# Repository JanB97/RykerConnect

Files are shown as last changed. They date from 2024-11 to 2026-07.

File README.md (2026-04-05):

# RykerConnect
Addon Media Display for CanAm Ryker

> [!WARNING]
> Current Hardware Version (REV01) of the MainUnit has a hardware bug.
In my test, I did not connect the reset line of the display to a pin on the esp32. 
I did only connect it to the reset/enable pin of the esp. This seemed to be fine while testing, but with the production boards I am having problems with the initialization.
I would ***NOT*** recommend getting these boards produced right now.
> 
> **Update 05.04.2026**: It's fixed in software for the most part, it seems like it's working now, just a bit buggy on startup (you see weird or old images).
> I have created a Rev2 that uses a gpio as reset line, but this board is not tested, i have not ordered it and you will need to build the firmware yourseld, because you need to change the pinout from using no pin to IO15 for the display reset.

This Project contains a firmware for a esp32s3 that is build on PlattformIO and the Arduino Core, an Android Companion App to get data on the Display and a simple ESP32S3 Board design to fit within a 3D printed case.
I will publish all the projects; however, please keep in mind that I am neither a hardware designer nor a software engineer, so pretty much all of this is messy.
It works, but that is a miracle.
Originally I did intend for this to have many features (e.g., show the weather, maybe map navigation, and more), but my development skills are not good enough right now.

The current features are only:
- Display the current time
- Keep the time while turned off
- Display the current temperature (if Hardware is installed on the board)
- Display current battery percentage of the connected phone
- Display current battery percentage of the connected intercom
- Display 'Spotify' media information
- Display Youtube Music media information
- Display incoming notifications (mostly)
- Display current network status
- ota updated from github or with firmware.bin file.
- Settings for: Brightness, Batteries to show, notification display timeout
- Quick Screen Reset (in case it will still bug out with the newest firmware and only display on one side of the oled)

Things I want to add/fix:
- Notifications are currently mostly working, but sometimes apps do random things and I think the android app needs some work to handle that.

Things to add to REV3 Hardware:
- similar to REV2 extend "empty" space around and under temp sensor, to help it not warm up because of the casing and/or ESP32
- add 3 wire (V, GND, S) connector for external DS18B20 (technically possible with REV1 through the exposed pins

REV3 is most likely (if at all) the next hardware rev i am going to build, as my REV1 is working good enough now, and there is no reason to build rev2 without the external sensor now.

> [!NOTE]
> You will need Programming and Hardware knowlage to get this to work right now, I don't think I can really support this right now, so please ho ahead on your own risk.
> If you can and are willing to help with the board design and programming, feel free to help, I am glad for every help on this!

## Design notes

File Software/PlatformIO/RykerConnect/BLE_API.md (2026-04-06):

# RykerConnect BLE API Documentation

## Overview

The RykerConnect MainUnit uses Bluetooth Low Energy (BLE) with NimBLE stack on an ESP32. The device advertises as **"RykerConnect-MainUnit"** and uses a **6-digit numeric pairing PIN** (display-only IO capability).

- **Bonding:** Enabled (bond + MITM protection)
- **TX Power:** +9 dBm
- **HID:** Registered as Gamepad (Appearance: `0x0180`, 1 button)

## Connection Parameters

After connection, the ESP requests fast connection parameters:
- Min Interval: 7.5ms (6 × 1.25ms)
- Max Interval: 15ms (12 × 1.25ms)
- Latency: 0
- Timeout: 1000ms (100 × 10ms)

---

## BLE Watchdog

If BLE is connected but **no characteristic is written for 10 minutes** (600,000 ms), the ESP force-disconnects the client. Any write resets the watchdog timer.

---

## Quick Reference — All Characteristics

| # | Name | UUID | Permissions |
|---|---|---|---|
| 1 | Time | `a41dcc81-d45e-4445-99bb-38c37c1ef1c8` | READ, WRITE |
| 2 | Network Status | `49c7fba8-9ba7-474b-b8a5-a5431e057e23` | WRITE |
| 3 | Phone Battery | `1f74ccf5-376a-40b6-ab60-7b1c5efbf652` | WRITE |
| 4 | Intercom Battery | `85546838-6ae5-45cb-aa2f-4c8af50d17d4` | WRITE |
| 5 | Media Data | `dcadc0d8-24ed-40ed-952b-5d1c872a69aa` | WRITE, WRITE\_NR |
| 6 | Notification | `755cf5b1-ded3-4c7b-a6fc-8c5ce2f99fdb` | WRITE + ENC + AUTHEN |
| 7 | Display Brightness | `7bc28f30-10bc-46e2-b84b-96e0545c2f5c` | READ, WRITE |
| 8 | Screen Selection | `62dbb02d-4a3a-452e-b753-02bcb2272b9d` | READ, WRITE |
| 9 | Settings | `05f7c3e4-daac-4953-8c71-20eacdf0c7a1` | READ + ENC + AUTHEN, WRITE + ENC + AUTHEN |
| 10 | Firmware Update (OTA) | `1d1306c5-98d9-4998-8dfd-35136295575f` | WRITE + ENC + AUTHEN |
| 11 | Firmware Reset | `18cb54fe-45e8-4819-a262-24b731c8b236` | WRITE + AUTHEN |
| 12 | Display Reinit | `3a6e4b2c-8f71-4d09-b5a3-c7e2f1d08a94` | WRITE |
| 13 | Firmware Version | `fb2385da-5290-4513-bb0c-6d0b21de619a` | READ |
| 14 | Hardware Version | `3ae9aece-1b67-4281-a53b-748adf23f484` | READ |
| 15 | Volume | `c4e83b7d-5a12-4f8e-b9d6-3e7f1c2a4b8d` | WRITE, WRITE\_NR |

---

## Service

| Name | UUID |
|---|---|
| RykerConnect Service | `db7ba582-229a-4b96-9000-cf0f69f86f73` |

---

## Characteristics

### 1. Time

| Property | Value |
|---|---|
| UUID | `a41dcc81-d45e-4445-99bb-38c37c1ef1c8` |
| Permissions | READ, WRITE |

**Write** – Set the RTC clock time.

| Byte | Type | Description |
|---|---|---|
| 0 | uint8_t | Hour (0–23) |
| 1 | uint8_t | Minute (0–59) |
| 2 | uint8_t | Second (0–59) |

Total: **3 bytes**

**Read** – Returns a placeholder string (not the current time).

---

### 2. Network Status

| Property | Value |
|---|---|
| UUID | `49c7fba8-9ba7-474b-b8a5-a5431e057e23` |
| Permissions | WRITE |

**Write** – Send mobile network signal and type.

| Byte | Type | Description |
|---|---|---|
| 0 | uint8_t | Signal strength (raw value) |
| 1 | uint8_t | Network type code |

Total: **2 bytes** (uint16_t, little-endian)

Network type codes:
| Code | Display |
|---|---|
| 0 | `!` (no signal) |
| 1 | `G` (GPRS) |
| 2 | `E` (EDGE) |
| 3 | `3G` |
| 4 | `H` (HSPA) |
| 5 | `H+` (HSPA+) |
| 6 | `4G` (LTE) |
| 7 | `4G+` (LTE-A) |
| 8 | `5G` |
| 9 | `5G+` |

---

### 3. Phone Battery

| Property | Value |
|---|---|
| UUID | `1f74ccf5-376a-40b6-ab60-7b1c5efbf652` |
| Permissions | WRITE |

**Write** – Send phone battery level and charging status.

| Byte | Type | Description |
|---|---|---|
| 0 | int8_t | Battery level (0–100, or negative) |
| 1 | uint8_t | Charging status (0 = not charging, 1 = charging) |

Total: **2 bytes** (int16_t, little-endian)

**Low battery warning:** If level ≤ `low_battery_threshold_phone`, a popup is shown. The warning triggers **only once per threshold crossing** — the flag resets only when the battery rises above the threshold again. Popup duration = `warning_popup_duration` seconds.

---

### 4. Intercom Battery

| Property | Value |
|---|---|
| UUID | `85546838-6ae5-45cb-aa2f-4c8af50d17d4` |
| Permissions | WRITE |

**Write** – Send intercom battery level.

| Byte | Type | Description |
|---|---|---|
| 0 | uint8_t | Battery level (0–100) |

Total: **1 byte** (int8_t)

**Low battery warning:** Same one-time-per-crossing logic as for phone battery. No charging status for intercom.

---

### 5. Media Data

| Property | Value |
|---|---|
| UUID | `dcadc0d8-24ed-40ed-952b-5d1c872a69aa` |
| Permissions | WRITE, WRITE_NR (write without response) |

**Write** – Send current media playback state.

| Byte | Type | Description |
|---|---|---|
| 0 | uint8_t | Playstate: 0 = paused, 1 = playing |
| 1–2 | uint16_t (LE) | Current position in seconds |
| 3–4 | uint16_t (LE) | Total track length in seconds |
| 5+ | String | Title + `0x03` (ETX separator) + Artist |

Total: **5+ bytes** (minimum 5 without title/artist)

All fields are **little-endian**, consistent with all other characteristics.

String format for bytes 5+:
```
<Title>\x03<Artist>
```

---

### 6. Notification

| Property | Value |
|---|---|
| UUID | `755cf5b1-ded3-4c7b-a6fc-8c5ce2f99fdb` |
| Permissions | WRITE (encrypted + authenticated) |

**Write** – Display a notification popup on the device.

String format:
```
<Type>\x03<Title>\x03<Text>
```

Fields are separated by `0x03` (ETX byte). All fields are UTF-8 strings. The notification is displayed for a configurable duration (`notification_interval` in settings).

---

### 7. Display Brightness

| Property | Value |
|---|---|
| UUID | `7bc28f30-10bc-46e2-b84b-96e0545c2f5c` |
| Permissions | READ, WRITE |

**Write** – Set display brightness (contrast) for both OLEDs.

| Byte | Type | Description |
|---|---|---|
| 0 | uint8_t | Brightness (0–255) |

**Read** – Returns the current brightness value (uint8_t).

---

### 8. Screen Selection

| Property | Value |
|---|---|
| UUID | `62dbb02d-4a3a-452e-b753-02bcb2272b9d` |
| Permissions | READ, WRITE |

**Write** – Switch the active screen layout.

| Byte | Type | Description |
|---|---|---|
| 0 | uint8_t | Screen index |

Screen indices:
| Value | Screen |
|---|---|
| 0 | Default (fullscreen clock left, temperature right) |
| 1 | Media screen |
| 2 | Split screen |

**Read** – Returns the current screen index (uint8_t).

---

### 9. Settings

| Property | Value |
|---|---|
| UUID | `05f7c3e4-daac-4953-8c71-20eacdf0c7a1` |
| Permissions | READ (encrypted + authenticated), WRITE (encrypted + authenticated) |

**Read** – Returns the full EEPROM_Struct (all settings as raw bytes). The struct is packed, so it can be directly parsed byte by byte.

**EEPROM_Struct layout (read response):**

| Offset | Size | Type | Field | Description |
|---|---|---|---|---|
| **Brightness** |
| 0 | 1 | bool | adaptive_brightness | Adaptive brightness enabled |
| 1 | 1 | uint8_t | display_brightness | Display brightness (0–255) |
| 2–3 | 2 | uint16_t (LE) | auto_brightness_adc_low | ADC value (0–4095) below which min brightness is applied (default: 200) |
| 4–5 | 2 | uint16_t (LE) | auto_brightness_adc_high | ADC value (0–4095) above which max brightness is applied (default: 3500) |
| **Screen** |
| 6 | 1 | uint8_t | screen | Active screen index (0=Default, 1=Media, 2=Split) |
| 7 | 1 | uint8_t | sub_screen | Sub-screen index |
| **Battery Icon** |
| 8 | 1 | bool | battery_icon_selection[0] | Show phone battery icon |
| 9 | 1 | bool | battery_icon_selection[1] | Show intercom battery icon |
| 10 | 1 | bool | battery_icon_selection[2] | (reserved) |
| 11 | 1 | bool | battery_icon_selection[3] | (reserved) |
| 12 | 1 | int8_t | battery_icon_first | First battery icon to show |
| 13–16 | 4 | uint32_t (LE) | battery_icon_interval | Battery icon rotation interval (ms) |
| **Low Battery Warning** |
| 17 | 1 | uint8_t | low_battery_threshold_phone | Phone low-battery warning threshold % (default: 20) |
| 18 | 1 | uint8_t | low_battery_threshold_intercom | Intercom low-battery warning threshold % (default: 20) |
| 19 | 1 | uint8_t | warning_popup_duration | Warning popup display duration in seconds (default: 5) |
| **Other** |
| 20–23 | 4 | uint32_t (LE) | notification_interval | Notification display duration (ms) |
| 24–27 | 4 | float (LE) | temp_calibration | Temperature offset in °C (subtracted from sensor) |
| **Reserved** |
| 28–37 | 10 | uint8_t[10] | reserved | Reserved for future use |
| **CRC** |
| 38–41 | 4 | uint32_t (LE) | crc | CRC32 checksum |

Total: **42 bytes**

**Write** – Update all settings. Send **38 bytes** (struct without CRC). The CRC is recalculated automatically. Settings are persisted to flash (NVS/Preferences).

Write payload (38 bytes = struct size minus CRC):

| Offset | Size | Type | Field | Notes |
|---|---|---|---|---|
| 0 | 1 | bool | adaptive_brightness | |
| 1 | 1 | uint8_t | display_brightness | |
| 2–3 | 2 | uint16_t (LE) | auto_brightness_adc_low | Send `0` to keep current value |
| 4–5 | 2 | uint16_t (LE) | auto_brightness_adc_high | Send `0` to keep current value |
| 6 | 1 | uint8_t | screen | |
| 7 | 1 | uint8_t | sub_screen | |
| 8–11 | 4 | bool[4] | battery_icon_selection | |
| 12 | 1 | int8_t | battery_icon_first | |
| 13–16 | 4 | uint32_t (LE) | battery_icon_interval | |
| 17 | 1 | uint8_t | low_battery_threshold_phone | |
| 18 | 1 | uint8_t | low_battery_threshold_intercom | |
| 19 | 1 | uint8_t | warning_popup_duration | Seconds (default: 5) |
| 20–23 | 4 | uint32_t (LE) | notification_interval | |
| 24–27 | 4 | float (LE) | temp_calibration | Temperature offset in °C (subtracted from sensor) |
| 28–37 | 10 | uint8_t[10] | reserved | Send `0` |

**Note:** `crc` is NOT included in the write payload. The ESP expects exactly `sizeof(EEPROM_Struct) - sizeof(uint32_t)` = **38 bytes**. ADC thresholds are only updated if `adc_high > adc_low` and both are non-zero. `temp_calibration` is applied directly and subtracted from every sensor reading.

---

### 10. Firmware Update (OTA)

| Property | Value |
|---|---|
| UUID | `1d1306c5-98d9-4998-8dfd-35136295575f` |
| Permissions | WRITE (encrypted + authenticated) |

**Write** – Start WiFi and OTA update process.

String format (two variants):

**Browser-based OTA (no download URL):**
```
<SSID>\x03<Password>
```
The ESP connects to WiFi and starts a web server at `http://RykerConnect.local` for manual firmware upload via browser.

**Direct download OTA:**
```
<SSID>\x03<Password>\x03<Firmware_URL>
```
The ESP connects to WiFi and automatically downloads & flashes the firmware from the given URL. Both `http://` and `https://` are supported (GitHub Releases URLs work). Falls back to browser OTA on failure.

Fields are separated by `0x03` (ETX byte).

---

### 11. Firmware Reset

| Property | Value |
|---|---|
| UUID | `18cb54fe-45e8-4819-a262-24b731c8b236` |
| Permissions | WRITE (authenticated) |

**Write** – Factory reset the device (if correct PIN is provided), or cancel a pending reset.

| Byte | Type | Description |
|---|---|---|
| 0–1 | uint16_t (LE) | Reset PIN (or `0` to cancel) |

- **Value `0`:** Cancels a pending reset and hides the reset popup on the display.
- **Correct PIN:** Settings are reset and ESP restarts.
- **Wrong PIN:** A new PIN is generated and displayed.

A random 4-digit PIN (1000–9999) is generated at boot and shown on the display when a wrong PIN is sent.

---

### 12. Display Reinit

| Property | Value |
|---|---|
| UUID | `3a6e4b2c-8f71-4d09-b5a3-c7e2f1d08a94` |
| Permissions | WRITE |

**Write** – Reinitialize both OLED displays. Useful when a display fails to initialize at boot.

Send any value (content is ignored). The ESP will:
1. Reset CS pins
2. Initialize displays with slow SPI clock (8 MHz)
3. Re-initialize with fast SPI clock (60 MHz)
4. Restore brightness from saved settings

---

### 13. Firmware Version

| Property | Value |
|---|---|
| UUID | `fb2385da-5290-4513-bb0c-6d0b21de619a` |
| Permissions | READ |

**Read** – Returns the firmware version as a raw 16-bit integer.

| Byte | Type | Description |
|---|---|---|
| 0–1 | uint16_t (LE) | Firmware version (e.g. `0x0004` = V00.04) |

The version value corresponds to the `VERSION` compile-time constant. To display it in `Vxx.yy` format:
- High byte = major (`(version >> 8) & 0xFF`)
- Low byte = minor (`version & 0xFF`)

---

### 14. Hardware Version

| Property | Value |
|---|---|
| UUID | `3ae9aece-1b67-4281-a53b-748adf23f484` |
| Permissions | READ |

**Read** – Returns the hardware version as a UTF-8 string (e.g. `"ESP32S3-REV01"`).

---

### 15. Volume

| Property | Value |
|---|---|
| UUID | `c4e83b7d-5a12-4f8e-b9d6-3e7f1c2a4b8d` |
| Permissions | WRITE |

**Write** – Send the current volume level. Displays a popup with percentage and progress bar (duration configurable via `warning_popup_duration` setting).

| Byte | Type | Description |
|---|---|---|
| 0 | uint8_t | Volume level (0 = Mute, 1–100 = percentage) |

Total: **1 byte**

---

## Data Encoding Notes

- **Byte order:** All multi-byte integers use **little-endian**.
- **String separator:** `0x03` (ETX) is used as field delimiter in all string-based characteristics.
- **String encoding:** UTF-8.

## Behavior Notes

**Low Battery Warning:** Triggers once when battery first falls below the threshold. The trigger flag resets only after the battery recovers above the threshold — preventing repeated popups on every BLE update.

**Volume Popup:** Shown on every Volume write. Duration = `warning_popup_duration` seconds.

**Auto-Brightness:** EMA-smoothed ADC reading (α=0.05, 100 ms interval) from light sensor on ADC pin 7. Mapped linearly from `[adc_low, adc_high]` → brightness `[25, 255]`. Minimum brightness is **25** (never goes below). Manual Brightness characteristic writes are ignored while `adaptive_brightness` is enabled.

---

## Android / Kotlin Implementation

### Constants

```kotlin
object RykerBLE {
    const val DEVICE_NAME            = "RykerConnect-MainUnit"
    const val SERVICE_UUID           = "db7ba582-229a-4b96-9000-cf0f69f86f73"
    const val TIME_UUID              = "a41dcc81-d45e-4445-99bb-38c37c1ef1c8"
    const val NETWORK_UUID           = "49c7fba8-9ba7-474b-b8a5-a5431e057e23"
    const val PHONE_BATTERY_UUID     = "1f74ccf5-376a-40b6-ab60-7b1c5efbf652"
    const val INTERCOM_BATTERY_UUID  = "85546838-6ae5-45cb-aa2f-4c8af50d17d4"
    const val MEDIA_DATA_UUID        = "dcadc0d8-24ed-40ed-952b-5d1c872a69aa"
    const val NOTIFICATION_UUID      = "755cf5b1-ded3-4c7b-a6fc-8c5ce2f99fdb"
    const val BRIGHTNESS_UUID        = "7bc28f30-10bc-46e2-b84b-96e0545c2f5c"
    const val SCREEN_UUID            = "62dbb02d-4a3a-452e-b753-02bcb2272b9d"
    const val SETTINGS_UUID          = "05f7c3e4-daac-4953-8c71-20eacdf0c7a1"
    const val FIRMWARE_UPDATE_UUID   = "1d1306c5-98d9-4998-8dfd-35136295575f"
    const val FIRMWARE_RESET_UUID    = "18cb54fe-45e8-4819-a262-24b731c8b236"
    const val DISPLAY_REINIT_UUID    = "3a6e4b2c-8f71-4d09-b5a3-c7e2f1d08a94"
    const val FIRMWARE_VERSION_UUID  = "fb2385da-5290-4513-bb0c-6d0b21de619a"
    const val HARDWARE_VERSION_UUID  = "3ae9aece-1b67-4281-a53b-748adf23f484"
    const val VOLUME_UUID            = "c4e83b7d-5a12-4f8e-b9d6-3e7f1c2a4b8d"
    const val SETTINGS_READ_SIZE     = 42  // full struct including CRC
    const val SETTINGS_WRITE_SIZE    = 38  // struct without CRC
}
```

### Write Helper

```kotlin
/** Queue BLE writes — only one can be in-flight at a time. */
fun BluetoothGatt.writeChar(uuid: String, data: ByteArray) {
    val svc  = getService(UUID.fromString(RykerBLE.SERVICE_UUID)) ?: return
    val char = svc.getCharacteristic(UUID.fromString(uuid)) ?: return
    char.writeType = BluetoothGattCharacteristic.WRITE_TYPE_DEFAULT
    char.value = data
    writeCharacteristic(char)
}

/** Fire-and-forget write (no BLE ACK) — use for frequent updates like Volume. */
fun BluetoothGatt.writeCharNR(uuid: String, data: ByteArray) {
    val svc  = getService(UUID.fromString(RykerBLE.SERVICE_UUID)) ?: return
    val char = svc.getCharacteristic(UUID.fromString(uuid)) ?: return
    char.writeType = BluetoothGattCharacteristic.WRITE_TYPE_NO_RESPONSE
    char.value = data
    writeCharacteristic(char)
}

// Android 13+ (API 33):
fun BluetoothGatt.writeChar33(uuid: String, data: ByteArray, noResponse: Boolean = false) {
    val svc  = getService(UUID.fromString(RykerBLE.SERVICE_UUID)) ?: return
    val char = svc.getCharacteristic(UUID.fromString(uuid)) ?: return
    val type = if (noResponse) BluetoothGattCharacteristic.WRITE_TYPE_NO_RESPONSE
               else BluetoothGattCharacteristic.WRITE_TYPE_DEFAULT
    writeCharacteristic(char, data, type)
}
```

### Sending Time

```kotlin
fun sendTime(gatt: BluetoothGatt) {
    val now = Calendar.getInstance()
    gatt.writeChar(RykerBLE.TIME_UUID, byteArrayOf(
        now.get(Calendar.HOUR_OF_DAY).toByte(),
        now.get(Calendar.MINUTE).toByte(),
        now.get(Calendar.SECOND).toByte()
    ))
}
```

### Sending Network Status

```kotlin
fun sendNetwork(gatt: BluetoothGatt, signalBars: Int, typeCode: Int) {
    // signalBars: 0–5 (icon level), typeCode: 0–9 (see network type table)
    gatt.writeChar(RykerBLE.NETWORK_UUID, byteArrayOf(
        signalBars.toByte(),
        typeCode.toByte()
    ))
}
```

### Sending Phone Battery

```kotlin
fun sendPhoneBattery(gatt: BluetoothGatt, level: Int, isCharging: Boolean) {
    val data = ByteBuffer.allocate(2).order(ByteOrder.LITTLE_ENDIAN)
        .put(level.toByte())
        .put(if (isCharging) 1.toByte() else 0.toByte())
        .array()
    gatt.writeChar(RykerBLE.PHONE_BATTERY_UUID, data)
}
```

### Sending Intercom Battery

```kotlin
fun sendIntercomBattery(gatt: BluetoothGatt, level: Int) {
    gatt.writeChar(RykerBLE.INTERCOM_BATTERY_UUID, byteArrayOf(level.toByte()))
}
```

### Sending Media Data

```kotlin
fun sendMediaData(
    gatt: BluetoothGatt,
    playing: Boolean,
    positionSec: Int,
    lengthSec: Int,
    title: String,
    artist: String
) {
    val titleBytes  = title.toByteArray(Charsets.UTF_8)
    val artistBytes = artist.toByteArray(Charsets.UTF_8)
    val buf = ByteBuffer.allocate(5 + titleBytes.size + 1 + artistBytes.size)
        .order(ByteOrder.LITTLE_ENDIAN)
    buf.put(if (playing) 1.toByte() else 0.toByte())  // [0] playstate
    buf.putShort(positionSec.toShort())                 // [1-2] little-endian
    buf.putShort(lengthSec.toShort())                   // [3-4] little-endian
    buf.put(titleBytes)
    buf.put(0x03.toByte())                              // ETX separator
    buf.put(artistBytes)
    gatt.writeChar(RykerBLE.MEDIA_DATA_UUID, buf.array())
}
```

### Sending a Notification

```kotlin
fun sendNotification(gatt: BluetoothGatt, type: String, title: String, text: String) {
    // type examples: "WhatsApp", "Instagram", "Discord", "Gmail", "Messages"
    gatt.writeChar(
        RykerBLE.NOTIFICATION_UUID,
        "$type\u0003$title\u0003$text".toByteArray(Charsets.UTF_8)
    )
}
```

### Setting Brightness

```kotlin
fun setBrightness(gatt: BluetoothGatt, brightness: Int) {
    // 0–255. No effect while adaptive_brightness is enabled.
    gatt.writeChar(RykerBLE.BRIGHTNESS_UUID, byteArrayOf(brightness.coerceIn(0, 255).toByte()))
}
```

### Setting Screen

```kotlin
fun setScreen(gatt: BluetoothGatt, screenIndex: Int) {
    // 0 = Default (clock+temp), 1 = Media, 2 = Split
    gatt.writeChar(RykerBLE.SCREEN_UUID, byteArrayOf(screenIndex.toByte()))
}
```

### Sending Volume

```kotlin
fun sendVolume(gatt: BluetoothGatt, volumePercent: Int) {
    // Use WRITE_NO_RESPONSE for fast, frequent volume updates (no BLE round-trip ACK).
    // 0 = Mute, 1–100 = percentage. Shows popup for warning_popup_duration seconds.
    gatt.writeCharNR(RykerBLE.VOLUME_UUID, byteArrayOf(volumePercent.coerceIn(0, 100).toByte()))
}
```

### Reading Settings (42 bytes)

```kotlin
fun parseSettings(data: ByteArray): RykerSettings {
    require(data.size >= 42) { "Settings response must be 42 bytes" }
    val buf = ByteBuffer.wrap(data).order(ByteOrder.LITTLE_ENDIAN)
    return RykerSettings(
        adaptiveBrightness    = buf.get().toInt() != 0,           // [0]
        displayBrightness     = buf.get().toInt() and 0xFF,        // [1]
        adcLow                = buf.short.toInt() and 0xFFFF,      // [2-3]
        adcHigh               = buf.short.toInt() and 0xFFFF,      // [4-5]
        screen                = buf.get().toInt() and 0xFF,         // [6]
        subScreen             = buf.get().toInt() and 0xFF,         // [7]
        batteryIcon0          = buf.get().toInt() != 0,            // [8]
        batteryIcon1          = buf.get().toInt() != 0,            // [9]
        // [10],[11] reserved bools — read and discard
        also { buf.get(); buf.get() },
        batteryIconFirst      = buf.get().toInt(),                  // [12] signed
        batteryIconInterval   = buf.int,                            // [13-16] ms
        lowBatteryPhone       = buf.get().toInt() and 0xFF,         // [17] %
        lowBatteryIntercom    = buf.get().toInt() and 0xFF,         // [18] %
        warningPopupDuration  = buf.get().toInt() and 0xFF,         // [19] seconds
        notificationInterval  = buf.int,                            // [20-23] ms
        tempCalibration       = buf.float,                          // [24-27]
        // [28-37] reserved — skip, [38-41] CRC — skip
    )
}
```

### Writing Settings (38 bytes)

```kotlin
fun buildSettingsPayload(s: RykerSettings): ByteArray {
    val data = ByteArray(RykerBLE.SETTINGS_WRITE_SIZE)  // 38 bytes, no CRC
    val buf  = ByteBuffer.wrap(data).order(ByteOrder.LITTLE_ENDIAN)
    buf.put(if (s.adaptiveBrightness) 1 else 0)        // [0]
    buf.put(s.displayBrightness.toByte())               // [1]
    buf.putShort(s.adcLow.toShort())                    // [2-3]  0 = keep current
    buf.putShort(s.adcHigh.toShort())                   // [4-5]  0 = keep current
    buf.put(s.screen.toByte())                          // [6]
    buf.put(s.subScreen.toByte())                       // [7]
    buf.put(if (s.batteryIcon0) 1 else 0)              // [8]
    buf.put(if (s.batteryIcon1) 1 else 0)              // [9]
    buf.put(0)                                          // [10] reserved
    buf.put(0)                                          // [11] reserved
    buf.put(s.batteryIconFirst.toByte())                // [12]
    buf.putInt(s.batteryIconInterval)                   // [13-16] ms
    buf.put(s.lowBatteryPhone.toByte())                 // [17] %
    buf.put(s.lowBatteryIntercom.toByte())              // [18] %
    buf.put(s.warningPopupDuration.toByte())            // [19] seconds
    buf.putInt(s.notificationInterval)                  // [20-23] ms
    buf.putFloat(0f)                                    // [24-27] temp_calibration: ESP ignores writes
    repeat(10) { buf.put(0) }                           // [28-37] reserved
    return data
}

fun writeSettings(gatt: BluetoothGatt, s: RykerSettings) {
    gatt.writeChar(RykerBLE.SETTINGS_UUID, buildSettingsPayload(s))
}
```

### Reading Firmware / Hardware Version

```kotlin
// Trigger a read — handle result in onCharacteristicRead()
fun readVersions(gatt: BluetoothGatt) {
    val svc = gatt.getService(UUID.fromString(RykerBLE.SERVICE_UUID)) ?: return
    gatt.readCharacteristic(svc.getCharacteristic(UUID.fromString(RykerBLE.FIRMWARE_VERSION_UUID)))
    // Wait for onCharacteristicRead before issuing next read!
}

// In BluetoothGattCallback.onCharacteristicRead():
override fun onCharacteristicRead(gatt: BluetoothGatt, char: BluetoothGattCharacteristic, status: Int) {
    if (status != BluetoothGatt.GATT_SUCCESS) return
    val data = char.value
    when (char.uuid.toString().lowercase()) {
        RykerBLE.FIRMWARE_VERSION_UUID.lowercase() -> {
            val buf   = ByteBuffer.wrap(data).order(ByteOrder.LITTLE_ENDIAN)
            val ver   = buf.short.toInt() and 0xFFFF  // e.g. 0x0006
            val major = (ver shr 8) and 0xFF           // 0
            val minor = ver and 0xFF                   // 6
            val text  = "v$major.$minor"               // "v0.6"
        }
        RykerBLE.HARDWARE_VERSION_UUID.lowercase() -> {
            val hw = String(data, Charsets.UTF_8)      // "ESP32S3-REV01"
        }
        RykerBLE.SETTINGS_UUID.lowercase() -> {
            val settings = parseSettings(data)         // 42 bytes
        }
    }
}
```

### OTA Update

```kotlin
// Variant A — Browser upload (no URL):
fun startOtaBrowser(gatt: BluetoothGatt, ssid: String, password: String) {
    gatt.writeChar(RykerBLE.FIRMWARE_UPDATE_UUID, "$ssid\u0003$password".toByteArray())
    // Device connects to WiFi and shows IP on screen.
    // Open http://<ip> (or http://RykerConnect.local) in browser, upload .bin file.
}

// Variant B — Direct download (HTTP and HTTPS supported, e.g. GitHub Releases):
fun startOtaDownload(gatt: BluetoothGatt, ssid: String, password: String, url: String) {
    gatt.writeChar(
        RykerBLE.FIRMWARE_UPDATE_UUID,
        "$ssid\u0003$password\u0003$url".toByteArray()
    )
}
```

### Factory Reset

```kotlin
fun sendResetPin(gatt: BluetoothGatt, pin: Int) {
    // pin = 0 → cancel and hide popup
    // pin = 4-digit value shown on display → reset all settings and reboot
    // any other value → new PIN generated and shown on display
    val data = ByteBuffer.allocate(2).order(ByteOrder.LITTLE_ENDIAN)
        .putShort(pin.toShort()).array()
    gatt.writeChar(RykerBLE.FIRMWARE_RESET_UUID, data)
}
```

### Reinitialize Displays

```kotlin
fun reinitDisplays(gatt: BluetoothGatt) {
    gatt.writeChar(RykerBLE.DISPLAY_REINIT_UUID, byteArrayOf(0x01))
}
```

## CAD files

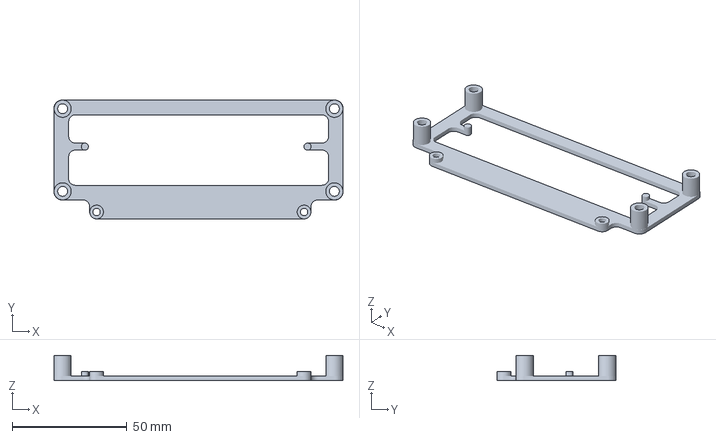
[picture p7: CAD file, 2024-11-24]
CAD/3MF/Developement/RykerConnect - DevMount-Mount V1.3mf
125.9 x 51.8 x 11.0 mm

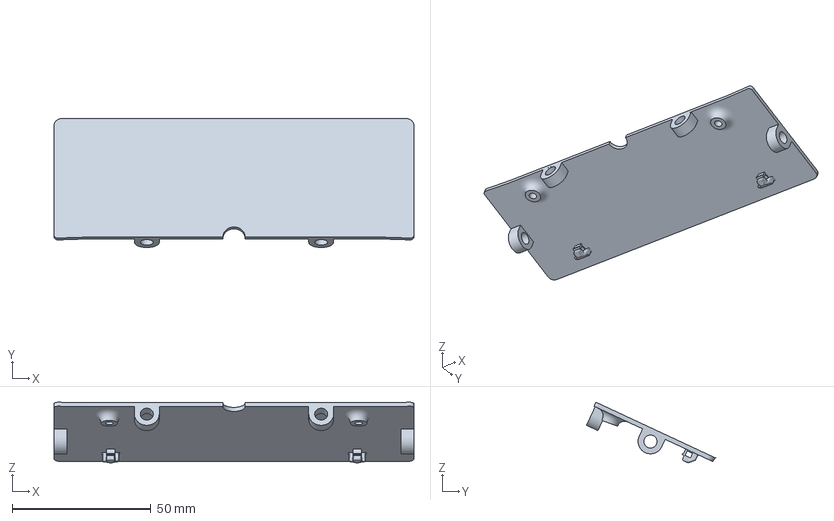
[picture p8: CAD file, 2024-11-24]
CAD/3MF/RykerMount/PCB-Mount.-Back V1.3mf
130.0 x 46.6 x 21.9 mm
Körper10
Körper11
Körper7

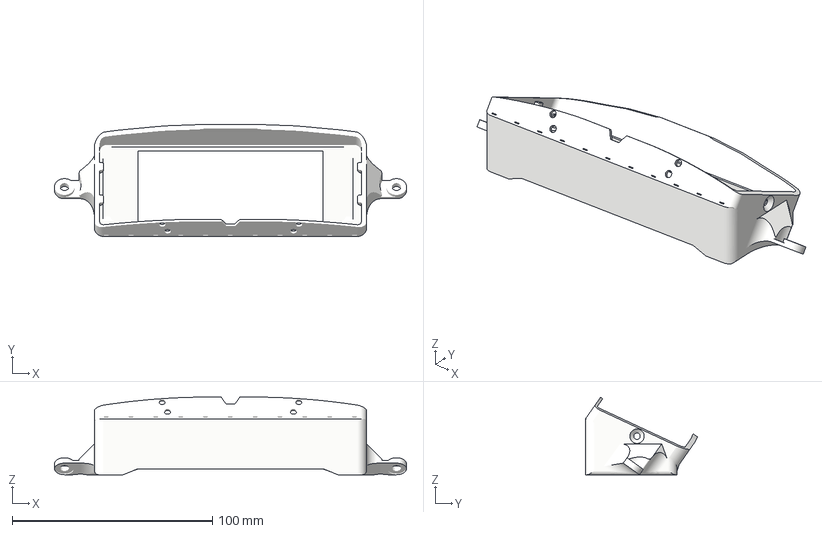
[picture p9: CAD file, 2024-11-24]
CAD/3MF/RykerMount/DisplayCover V1.3mf
176.0 x 56.0 x 38.8 mm

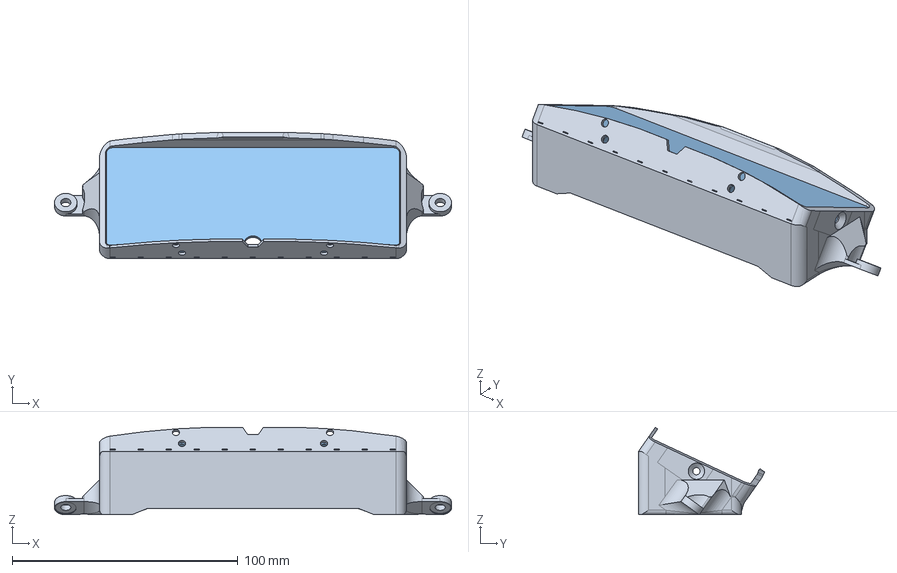
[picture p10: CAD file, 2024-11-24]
CAD/STEP/RykerConnect - Mount v1.step
176.0 x 56.0 x 38.8 mm
DisplayCover
PCB-Mount.-Back

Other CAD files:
CAD/STEP/RykerConnect - DevMount v1.step
CAD/Source/RykerConnect - DevMount v1.FCStd

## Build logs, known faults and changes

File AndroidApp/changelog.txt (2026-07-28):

V1.4.0: 
- support for multiple intercoms with a priority order: if several are connected, the topmost one reports its battery
- new app settings: Material You colors and a toggle for the debug Card
- battery reporting is now configurable: charge state changes are sent instantly while the level is polled at an adjustable 30 s to 10 min
- significantly fewer background wakeups by removing a permanent media session poll and idling the intercom loop when nothing is selected
- fix: connecting an intercom while the main unit was disconnected crashed the app, and the battery value was sent to the wrong device
- morph animations for settings, service and intercom now actually animate, plus support for the predictive back gesture
- updated to Android 17, Gradle 9.6.1 and Kotlin 2.4.10  

V1.3.1:
- bluetooth stability improvements.

V1.3.0:
- support Firmware V00.06 features and protocol changes
- new Design for Settings pages
- allow changing wifi credentials from DebugCard
- allow stopping parts of the service

V1.2.1:
- add debug option to send firmware update to BLE-address withouth device connection

V1.2:
- fix wifi credentials not beeing saved / not beeing display
- added changelog in firmware update view.
- add button listener to "Update available" tag
- bugfixes to "select / reselect device" function

V1.1:
- fix wifi credential fields and state
- fix latest firmware was not selected

V1.0:
- initial full release

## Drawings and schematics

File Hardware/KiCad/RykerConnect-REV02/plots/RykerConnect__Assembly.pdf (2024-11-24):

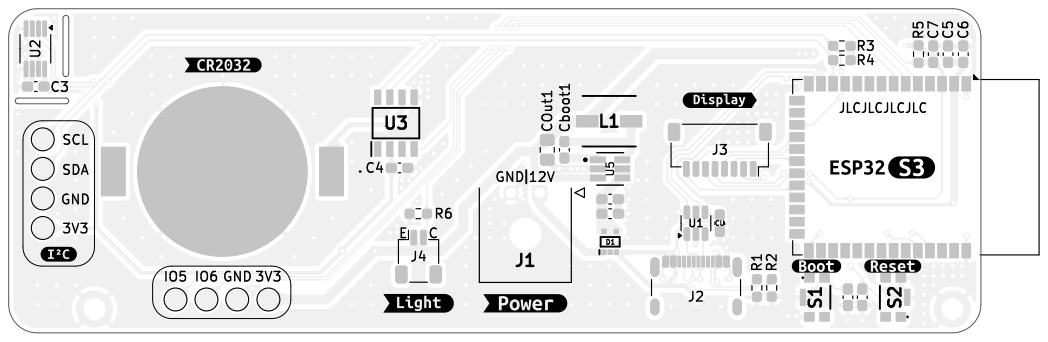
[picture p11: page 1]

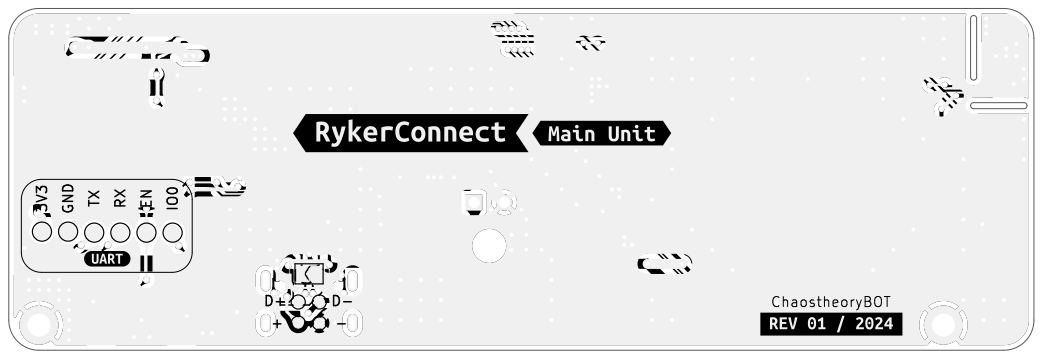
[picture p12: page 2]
D Date: KiCad; E.D.A. 8.0.1 Size: A4; Rev:; Id: 1/1 Title: File: RykerConnect.kicad_pcb Sheet: AISLER; Project; ID: QIOOLVKT; ChaostheoryBOT ³V³ GND TXRXENIO⁰

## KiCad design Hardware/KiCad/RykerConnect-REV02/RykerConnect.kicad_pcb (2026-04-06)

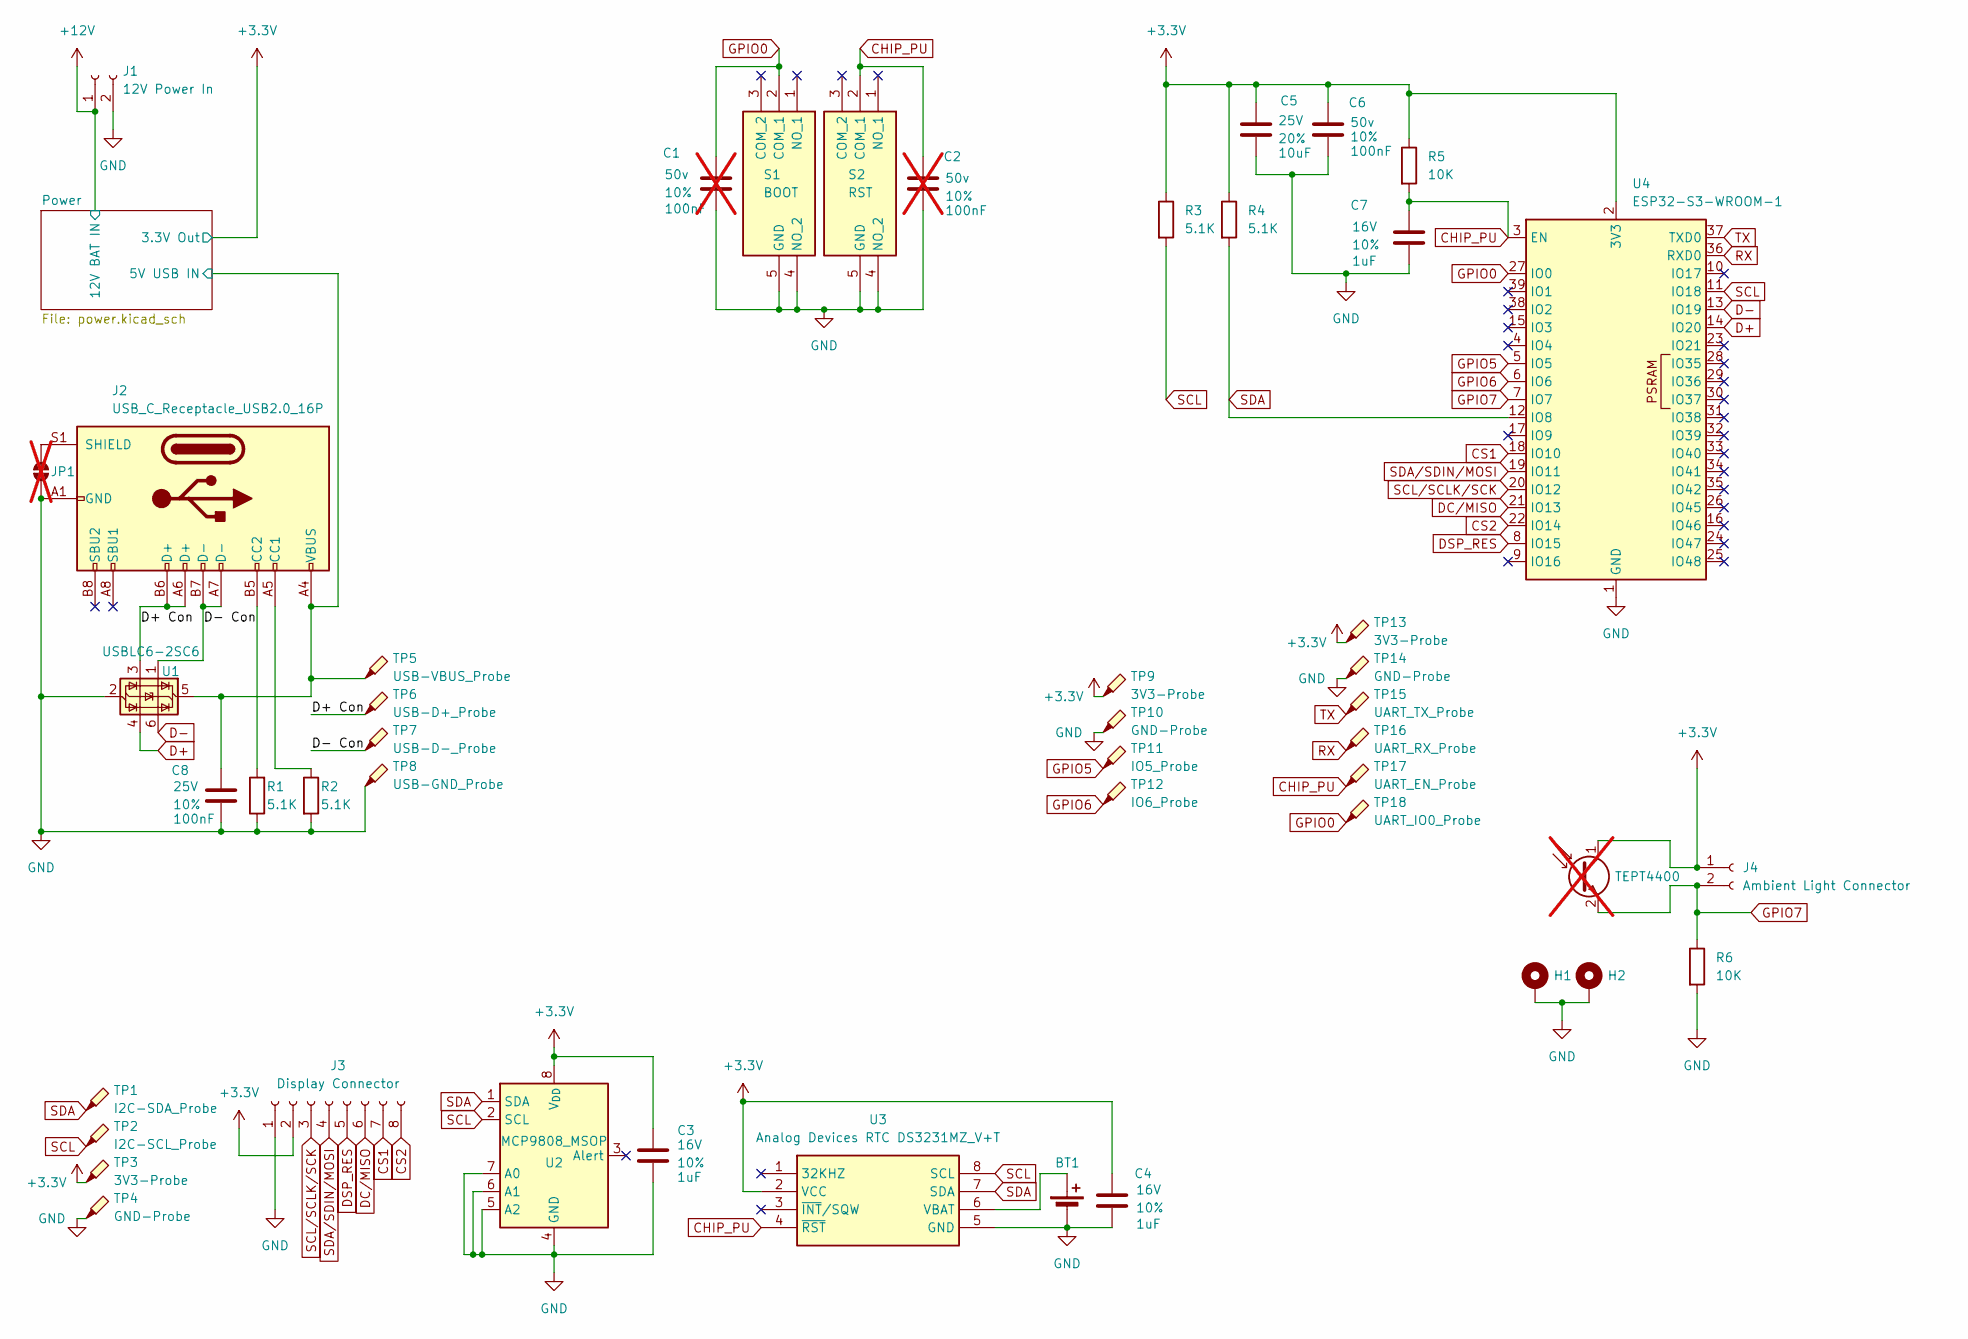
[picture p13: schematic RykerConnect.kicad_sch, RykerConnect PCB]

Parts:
BT1: Holders Linx CR2032; BATHLD001
C1, C2: 100nF; C_0603_1608Metric_Pad1.08x0.95mm_HandSolder; Voltage 50v; Tolerance 10%; not fitted
C3, C4, C7: 1uF; C_0603_1608Metric_Pad1.08x0.95mm_HandSolder; Voltage 16V; Tolerance 10%
C5: 10uF; C_0603_1608Metric_Pad1.08x0.95mm_HandSolder; Voltage 25V; Tolerance 20%
C6: 100nF; C_0603_1608Metric_Pad1.08x0.95mm_HandSolder; Voltage 50v; Tolerance 10%
C8: 100nF; C_0603_1608Metric_Pad1.08x0.95mm_HandSolder; Voltage 25V; Tolerance 10%
H1, H2: MountingHole_Pad; MountingHole_2.2mm_M2_ISO14580_Pad_TopBottom
J1: 12V Power In; 43650-02_00,01,02_
J2: USB_C_Receptacle_USB2.0_16P; USB_C_Receptacle_GCT_USB4105-xx-A_16P_TopMnt_Horizontal
J3: Display Connector; JST_SH_SM08B-SRSS-TB_1x08-1MP_P1.00mm_Horizontal
J4: Ambient Light Connector; JST_SH_SM02B-SRSS-TB_1x02-1MP_P1.00mm_Horizontal
JP1: SolderJumper_2_Open; R_0603_1608Metric_Pad0.98x0.95mm_HandSolder; not fitted
Q1: TEPT4400; LED_D3.0mm_Clear; not fitted
R1, R2, R3, R4: 5.1K; R_0805_2012Metric_Pad1.20x1.40mm_HandSolder
R5: 10K; R_0805_2012Metric_Pad1.20x1.40mm_HandSolder; Tolerance 1%
R6: 10K; R_0805_2012Metric_Pad1.20x1.40mm_HandSolder
S1: BOOT; 435451019820; Mouser Part Number 710-435451019820
S2: RST; 435451019820; Mouser Part Number 710-435451019820
TP1: I2C-SDA_Probe; TestPoint_Pad_D2.0mm
TP2: I2C-SCL_Probe; TestPoint_Pad_D2.0mm
TP3, TP9: 3V3-Probe; TestPoint_Pad_D2.0mm
TP4, TP10: GND-Probe; TestPoint_Pad_D2.0mm
TP5: USB-VBUS_Probe; TestPoint_Pad_D1.0mm
TP6: USB-D+_Probe; TestPoint_Pad_D1.0mm
TP7: USB-D-_Probe; TestPoint_Pad_D1.0mm
TP8: USB-GND_Probe; TestPoint_Pad_D1.0mm
TP11: IO5_Probe; TestPoint_Pad_D2.0mm
TP12: IO6_Probe; TestPoint_Pad_D2.0mm
TP13: 3V3-Probe; TestPoint_Pad_D1.5mm
TP14: GND-Probe; TestPoint_Pad_D1.5mm
TP15: UART_TX_Probe; TestPoint_Pad_D1.5mm
TP16: UART_RX_Probe; TestPoint_Pad_D1.5mm
TP17: UART_EN_Probe; TestPoint_Pad_D1.5mm
TP18: UART_IO0_Probe; TestPoint_Pad_D1.5mm
U1: USBLC6-2SC6; SOT-23-6
U2: MCP9808_MSOP; MSOP-8_3x3mm_P0.65mm
U3: Analog Devices RTC DS3231MZ_V+T; SOIC127P600X175-8N; Mouser Part Number 700-DS3231MZ/V+T
U4: ESP32-S3-WROOM-1

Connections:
+3.3V: C3.1, C4.1, C5.1, C6.1, J3.2, J4.1, Q1.1 (C), R3.1, R4.1, R5.1, TP3.1 (1_1), TP9.1 (1_1), TP13.1 (1_1), U2.8 (V_{DD}), U3.2 (VCC), U4.2 (3V3); also elsewhere on the board
+12V: J1.1; also elsewhere on the board
/D+ Con: J2.A6 (D+), J2.B6 (D+), TP6.1 (1_1), U1.3 (I/O2)
/D- Con: J2.A7 (D-), J2.B7 (D-), TP7.1 (1_1), U1.1 (I/O1)
/Power/5V USB IN: C8.1, J2.A4 (VBUS), J2.A9 (VBUS), J2.B4 (VBUS), J2.B9 (VBUS), TP5.1 (1_1), U1.5 (VBUS); also elsewhere on the board
CHIP_PU: C2.1, C7.1, R5.2, S2.2 (COM_1), TP17.1 (1_1), U3.4 (~RST), U4.3 (EN)
CS1: J3.7, U4.18 (IO10)
CS2: J3.8, U4.22 (IO14)
D+: U1.4 (I/O2), U4.14 (IO20)
D-: U1.6 (I/O1), U4.13 (IO19)
DC/MISO: J3.6, U4.21 (IO13)
DSP_RES: J3.5, U4.8 (IO15)
GND: BT1.2 (-), C1.2, C2.2, C3.2, C4.2, C5.2, C6.2, C7.2, C8.2, H1.1 (1_1), H2.1 (1_1), J1.2, J2.A1 (GND), J2.A12 (GND), J2.B1 (GND), J2.B12 (GND), J3.1, JP1.1 (A), R1.1, R2.2, R6.2, S1.4 (NO_2), S1.5 (GND), S2.4 (NO_2), S2.5 (GND), TP4.1 (1_1), TP8.1 (1_1), TP10.1 (1_1), TP14.1 (1_1), U1.2 (GND), U2.4 (GND), U2.5 (A2), U2.6 (A1), U2.7 (A0), U3.5 (GND), U4.1 (GND), U4.40 (GND), U4.41 (GND); also elsewhere on the board
GPIO0: C1.1, S1.2 (COM_1), TP18.1 (1_1), U4.27 (IO0)
GPIO5: TP11.1 (1_1), U4.5 (IO5)
GPIO6: TP12.1 (1_1), U4.6 (IO6)
GPIO7: J4.2, Q1.2 (E), R6.1, U4.7 (IO7)
unnamed: BT1.1 (+), U3.6 (VBAT)
unnamed: J2.A5 (CC1), R2.1
unnamed: J2.B5 (CC2), R1.2
unnamed: J2.S1 (SHIELD), JP1.2 (B)
RX: TP16.1 (1_1), U4.36 (RXD0)
SCL: R3.2, TP2.1 (1_1), U2.2 (SCL), U3.8 (SCL), U4.11 (IO18)
SCL/SCLK/SCK: J3.3, U4.20 (IO12)
SDA: R4.2, TP1.1 (1_1), U2.1 (SDA), U3.7 (SDA), U4.12 (IO8)
SDA/SDIN/MOSI: J3.4, U4.19 (IO11)
TX: TP15.1 (1_1), U4.37 (TXD0)

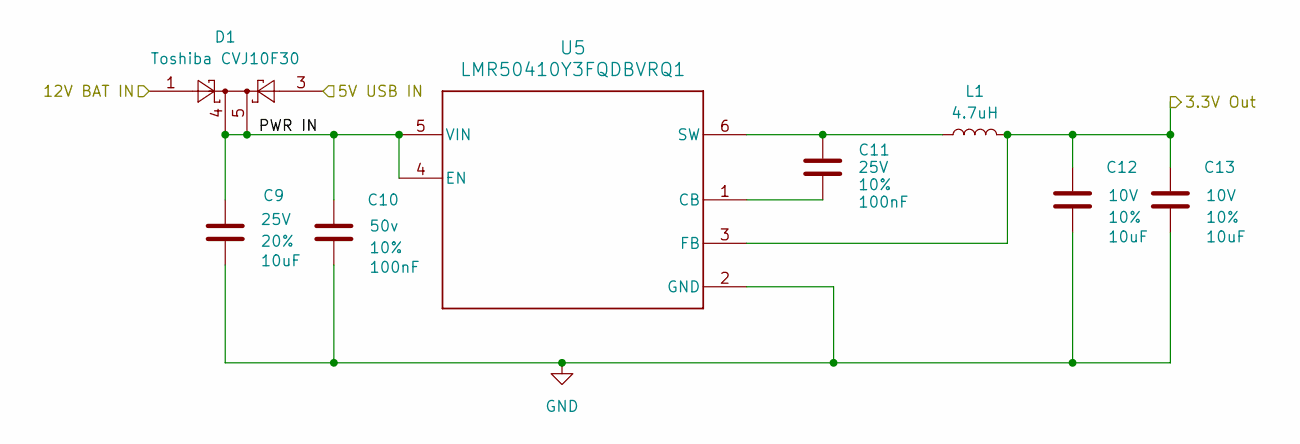
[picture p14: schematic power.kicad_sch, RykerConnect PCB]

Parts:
C9: 10uF; C_0603_1608Metric_Pad1.08x0.95mm_HandSolder; Voltage 25V; Tolerance 20%
C10: 100nF; C_0603_1608Metric_Pad1.08x0.95mm_HandSolder; Voltage 50v; Tolerance 10%
C11: 100nF; C_0603_1608Metric_Pad1.08x0.95mm_HandSolder; Voltage 25V; Tolerance 10%
C12, C13: 10uF; C_0805_2012Metric_Pad1.18x1.45mm_HandSolder; Voltage 10V; Tolerance 10%
D1: Toshiba CVJ10F30; SOTFL65P210X75-5N
L1: 4.7uH; INDPM5653X430N
U5: LMR50410Y3FQDBVRQ1; DBV0006A-IPC_A

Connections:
+3.3V: C12.1, C13.1, L1.2, U5.3 (FB); also elsewhere on the board
+12V: D1.1; also elsewhere on the board
/Power/5V USB IN: D1.3; also elsewhere on the board
/Power/PWR IN: C9.1, C10.1, D1.4, D1.5, U5.4 (EN), U5.5 (VIN)
GND: C9.2, C10.2, C12.2, C13.2, U5.2 (GND); also elsewhere on the board
unnamed: C11.2, U5.1 (CB)
unnamed: C11.1, L1.1, U5.6 (SW)

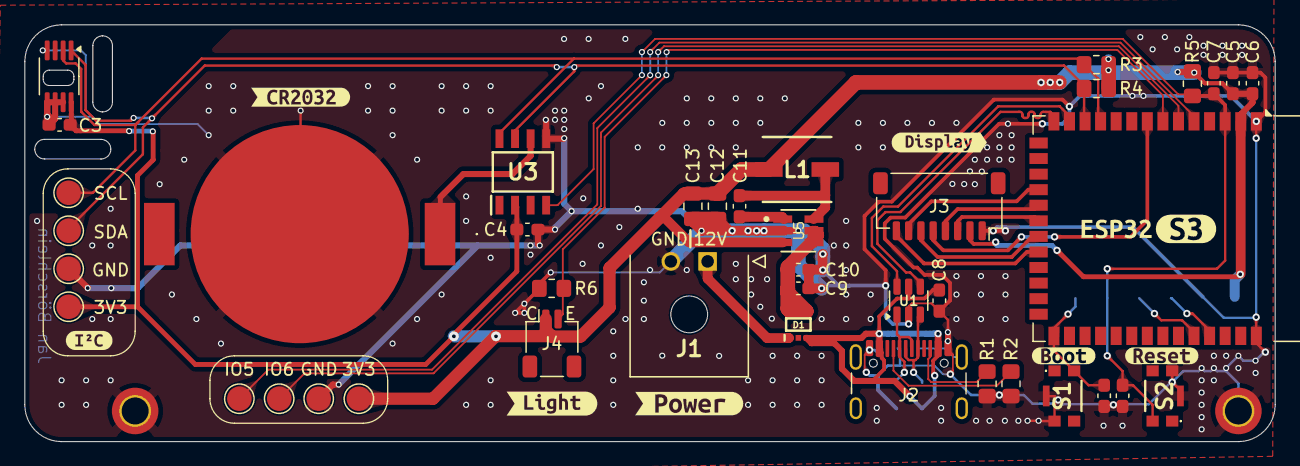
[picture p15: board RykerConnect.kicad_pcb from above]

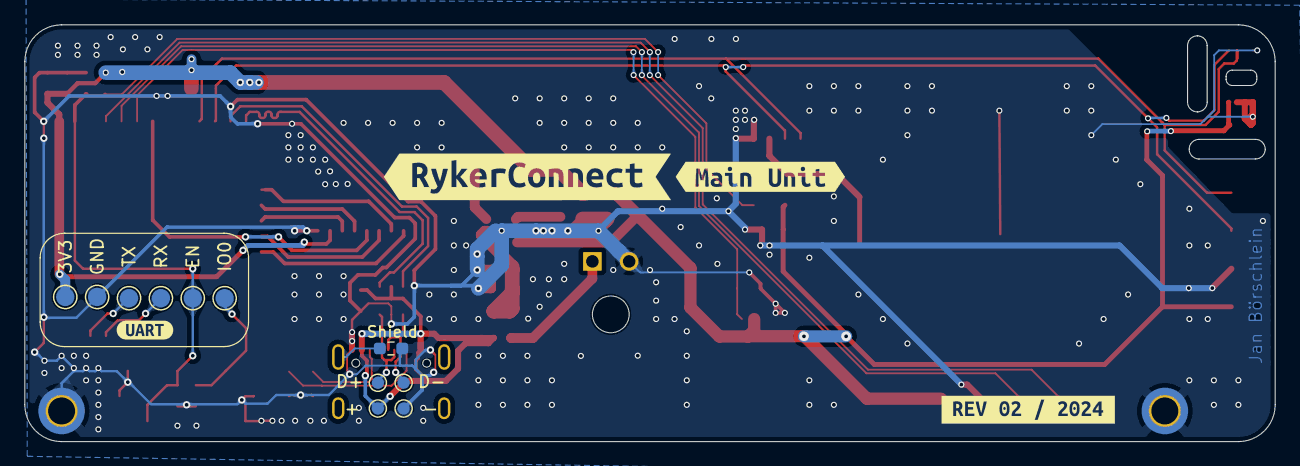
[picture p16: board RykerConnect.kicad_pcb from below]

Board: 2 copper layers, 102.0 x 34.0 mm, 67 parts (16 on the bottom side), 30 nets.

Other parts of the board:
kibuzzard-6647CFBD: G***; kibuzzard-6647CFBD
kibuzzard-66281C1F: G***; kibuzzard-66281C1F
kibuzzard-66281DA5: G***; kibuzzard-66281DA5
kibuzzard-66281FA1: G***; kibuzzard-66281FA1
kibuzzard-66282B71: G***; kibuzzard-66282B71
kibuzzard-66296C5A: G***; kibuzzard-66296C5A
kibuzzard-662805BB: G***; kibuzzard-662805BB
kibuzzard-662805C3: G***; kibuzzard-662805C3
kibuzzard-6628061E: G***; kibuzzard-6628061E
kibuzzard-6628064B: G***; kibuzzard-6628064B
kibuzzard-6628065E: G***; kibuzzard-6628065E
kibuzzard-66280634: G***; kibuzzard-66280634
kibuzzard-66281340: G***; kibuzzard-66281340

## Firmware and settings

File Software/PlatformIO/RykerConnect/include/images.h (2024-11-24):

#pragma once
#include <Arduino.h>

#define network_width 16
#define network_height 16
static unsigned char network0_bits[] = {
   0x00, 0xc0, 0x00, 0xa0, 0x00, 0x90, 0x00, 0x98, 0x00, 0x94, 0x00, 0x92,
   0x00, 0x93, 0x80, 0x92, 0x40, 0x92, 0x60, 0x92, 0x50, 0x92, 0x48, 0x92,
   0x4c, 0x92, 0x4a, 0x92, 0x49, 0x92, 0xff, 0xff };
static unsigned char network1_bits[] = {
   0x00, 0xc0, 0x00, 0xa0, 0x00, 0x90, 0x00, 0x98, 0x00, 0x94, 0x00, 0x92,
   0x00, 0x93, 0x80, 0x92, 0x40, 0x92, 0x60, 0x92, 0x50, 0x92, 0x48, 0x92,
   0x4c, 0x92, 0x4e, 0x92, 0x4f, 0x92, 0xff, 0xff };
static unsigned char network2_bits[] = {
   0x00, 0xc0, 0x00, 0xa0, 0x00, 0x90, 0x00, 0x98, 0x00, 0x94, 0x00, 0x92,
   0x00, 0x93, 0x80, 0x92, 0x40, 0x92, 0x60, 0x92, 0x70, 0x92, 0x70, 0x92,
   0x74, 0x92, 0x76, 0x92, 0x77, 0x92, 0xff, 0xff };
static unsigned char network3_bits[] = {
   0x00, 0xc0, 0x00, 0xa0, 0x00, 0x90, 0x00, 0x98, 0x00, 0x94, 0x00, 0x92,
   0x00, 0x93, 0x80, 0x93, 0x80, 0x93, 0xa0, 0x93, 0xb0, 0x93, 0xb0, 0x93,
   0xb4, 0x93, 0xb6, 0x93, 0xb7, 0x93, 0xff, 0xff };
static unsigned char network4_bits[] = {
   0x00, 0xc0, 0x00, 0xa0, 0x00, 0x90, 0x00, 0x98, 0x00, 0x9c, 0x00, 0x9c,
   0x00, 0x9d, 0x80, 0x9d, 0x80, 0x9d, 0xa0, 0x9d, 0xb0, 0x9d, 0xb0, 0x9d,
   0xb4, 0x9d, 0xb6, 0x9d, 0xb7, 0x9d, 0xff, 0xff };
static unsigned char network5_bits[] = {
   0x00, 0xc0, 0x00, 0xe0, 0x00, 0xe0, 0x00, 0xe8, 0x00, 0xec, 0x00, 0xec,
   0x00, 0xed, 0x80, 0xed, 0x80, 0xed, 0xa0, 0xed, 0xb0, 0xed, 0xb0, 0xed,
   0xb4, 0xed, 0xb6, 0xed, 0xb7, 0xed, 0xff, 0xff };



#define phone_16_width 10
#define phone_16_height 16
static unsigned char phone_16_bits[] PROGMEM = {
   0xfc, 0x00, 0x02, 0x01, 0x32, 0x01, 0x02, 0x01, 0x02, 0x01, 0x02, 0x01,
   0x02, 0x01, 0x02, 0x01, 0x02, 0x01, 0x02, 0x01, 0x02, 0x01, 0x02, 0x01,
   0x02, 0x01, 0x02, 0x01, 0x02, 0x01, 0xfc, 0x00 };

#define headset_16_width 10
#define headset_16_height 16
static unsigned char headset_16_bits[] PROGMEM = {
   0x00, 0x00, 0x7c, 0x00, 0x86, 0x01, 0x02, 0x01, 0x01, 0x02, 0x01, 0x02,
   0x01, 0x02, 0x03, 0x03, 0x03, 0x03, 0x03, 0x03, 0x03, 0x03, 0x00, 0x02,
   0x30, 0x02, 0xf0, 0x03, 0x30, 0x00, 0x00, 0x00 };

#define charging_width 5
#define charging_height 8
static unsigned char charging_bits[] PROGMEM = {0x04,0x0e,0x1b,0x00,0x00,0x04,0x0e,0x1b};

#define charging1_width 5
#define charging1_height 10
static unsigned char charging1_bits[] PROGMEM  = {0x10,0x18,0x0c,0x06,0x1e,0x0f,0x0c,0x06,0x03,0x01};


#define unkown_device_16_width 10
#define unkown_device_16_height 16
static unsigned char unkown_device_16_bits[] PROGMEM = {
   0xfe, 0x01, 0x01, 0x02, 0x79, 0x02, 0x01, 0x02, 0x01, 0x02, 0x79, 0x02,
   0xcd, 0x02, 0xcd, 0x02, 0xc1, 0x02, 0x61, 0x02, 0x31, 0x02, 0x31, 0x02,
   0x01, 0x02, 0x31, 0x02, 0x01, 0x02, 0xfe, 0x01 };


#define bluetooth_16_width 16
#define bluetooth_16_height 16
static unsigned char bluetooth_16_bits[] PROGMEM = {
   0x00, 0x00, 0x80, 0x00, 0x80, 0x01, 0x80, 0x02, 0x80, 0x04, 0xa0, 0x04,
   0xc0, 0x02, 0x80, 0x01, 0x80, 0x01, 0xc0, 0x02, 0xa0, 0x04, 0x80, 0x04,
   0x80, 0x02, 0x80, 0x01, 0x80, 0x00, 0x00, 0x00 };
#define bluetooth_16_verbunden_width 16
#define bluetooth_16_verbunden_height 16
static unsigned char bluetooth_16_verbunden_bits[] PROGMEM = {
   0x00, 0x00, 0x80, 0x00, 0x80, 0x01, 0x80, 0x02, 0x80, 0x04, 0xa0, 0x04,
   0xc0, 0x02, 0x8c, 0x31, 0x8c, 0x31, 0xc0, 0x02, 0xa0, 0x04, 0x80, 0x04,
   0x80, 0x02, 0x80, 0x01, 0x80, 0x00, 0x00, 0x00 };

/* SPOTIFY
#define spotify_30_width 30
#define spotify_30_height 30
static unsigned char spotify_30_bits[] PROGMEM = {
   0x00, 0xf0, 0x03, 0x00, 0x00, 0xfe, 0x1f, 0x00, 0x80, 0xff, 0x7f, 0x00,
   0xc0, 0xff, 0xff, 0x00, 0xe0, 0xff, 0xff, 0x01, 0xf0, 0xff, 0xff, 0x03,
   0xf8, 0xff, 0xff, 0x07, 0xfc, 0xff, 0xff, 0x0f, 0xfc, 0xff, 0xff, 0x0f,
   0x3e, 0x00, 0xf0, 0x1f, 0x1e, 0x00, 0x80, 0x1f, 0x3e, 0xfe, 0x01, 0x1e,
   0xfe, 0xff, 0x1f, 0x1e, 0xff, 0xff, 0x7f, 0x3e, 0x7f, 0x00, 0xf8, 0x3f,
   0x7f, 0x00, 0xe0, 0x3f, 0xff, 0xff, 0x83, 0x3f, 0xfe, 0xff, 0x9f, 0x1f,
   0xfe, 0x03, 0xff, 0x1f, 0xfe, 0x00, 0xf8, 0x1f, 0xfe, 0xfc, 0xe0, 0x1f,
   0xfc, 0xff, 0xe7, 0x0f, 0xfc, 0xff, 0xff, 0x0f, 0xf8, 0xff, 0xff, 0x07,
   0xf0, 0xff, 0xff, 0x03, 0xe0, 0xff, 0xff, 0x01, 0xc0, 0xff, 0xff, 0x00,
   0x80, 0xff, 0x7f, 0x00, 0x00, 0xfe, 0x1f, 0x00, 0x00, 0xe0, 0x01, 0x00 };
   */


#define musik_20_width 15
#define musik_20_height 20
static unsigned char musik_20_bits[] PROGMEM = {
   0x80, 0x03, 0x80, 0x0f, 0x80, 0x7f, 0x80, 0x7f, 0x80, 0x7f, 0x80, 0x78,
   0x80, 0x00, 0x80, 0x00, 0x80, 0x00, 0x80, 0x00, 0x80, 0x00, 0x80, 0x00,
   0x80, 0x00, 0xc0, 0x00, 0xfc, 0x00, 0xfe, 0x00, 0xff, 0x00, 0xff, 0x00,
   0x7e, 0x00, 0x3c, 0x00 };


#define notification_20_width 20
#define notification_20_height 20
static unsigned char notification_20_bits [] PROGMEM = {
	0x00, 0x06, 0x00, 0x00, 0x06, 0x00, 0x80, 0x1f, 0x00, 0xc0, 0x3f, 0x00, 0xe0, 0x7f, 0x00, 0xe0, 
	0x7f, 0x00, 0xf0, 0xff, 0x00, 0xf0, 0xff, 0x00, 0xf0, 0xff, 0x00, 0xf0, 0xff, 0x00, 0xf0, 0xff, 
	0x00, 0xf0, 0xff, 0x00, 0xf8, 0xff, 0x01, 0xf8, 0xff, 0x01, 0xfc, 0xff, 0x03, 0xfc, 0xff, 0x03, 
	0xfc, 0xff, 0x03, 0x00, 0x08, 0x00, 0x80, 0x1f, 0x00, 0x00, 0x0f, 0x00
};

static unsigned char mail_20_bits [] PROGMEM = {
	0x00, 0x00, 0x00, 0x00, 0x00, 0x00, 0x00, 0x00, 0x00, 0xfe, 0xff, 0x07, 0xff, 0xff, 0x0f, 0xff, 
	0xff, 0x0f, 0xfb, 0xff, 0x0d, 0xf7, 0x7f, 0x0f, 0x9f, 0x9f, 0x0f, 0x3f, 0xc7, 0x0f, 0x3f, 0xc0, 
	0x0f, 0xdf, 0xb9, 0x0f, 0xef, 0x7f, 0x0f, 0xf7, 0xff, 0x0e, 0xff, 0xff, 0x0f, 0xff, 0xff, 0x0f, 
	0xfe, 0xff, 0x07, 0x00, 0x00, 0x00, 0x00, 0x00, 0x00, 0x00, 0x00, 0x00
};

const unsigned char whatsapp_20_bits [] PROGMEM = {
	0x80, 0x1f, 0x00, 0xe0, 0x7f, 0x00, 0x38, 0xc0, 0x01, 0x1c, 0x80, 0x03, 0x0c, 0x00, 0x03, 0x46, 
	0x00, 0x06, 0xe6, 0x00, 0x04, 0xe3, 0x00, 0x0c, 0xe3, 0x00, 0x0c, 0xc3, 0x00, 0x0c, 0xc3, 0x00, 
	0x0c, 0x83, 0x11, 0x0c, 0x02, 0x7f, 0x0c, 0x06, 0x7c, 0x06, 0x06, 0x10, 0x06, 0x06, 0x00, 0x03, 
	0x06, 0x80, 0x01, 0x7e, 0xe0, 0x00, 0xff, 0x7f, 0x00, 0x03, 0x0f, 0x00
};

const unsigned char chat_20_bits [] PROGMEM = {
	0x00, 0x00, 0x00, 0xc0, 0x3f, 0x00, 0xf0, 0xff, 0x00, 0xf8, 0xff, 0x01, 0xfc, 0xff, 0x03, 0xfe, 
	0xff, 0x07, 0xfe, 0xff, 0x07, 0xfe, 0xff, 0x0f, 0xdf, 0xb9, 0x0f, 0x8f, 0x19, 0x0f, 0xdf, 0xb9, 
	0x0f, 0xff, 0xff, 0x0f, 0xfe, 0xff, 0x07, 0xfe, 0xff, 0x07, 0xfc, 0xff, 0x03, 0xfe, 0xff, 0x01, 
	0xfe, 0xff, 0x00, 0xfe, 0x3f, 0x00, 0x0f, 0x00, 0x00, 0x00, 0x00, 0x00
};

const unsigned char discord_20_bits [] PROGMEM = {
	0x00, 0x00, 0x00, 0x00, 0x00, 0x00, 0x40, 0x20, 0x00, 0xf8, 0xff, 0x01, 0xf8, 0xff, 0x01, 0xfc, 
	0xff, 0x03, 0xfc, 0xff, 0x03, 0xfe, 0xff, 0x07, 0xfe, 0xff, 0x07, 0x1f, 0x8f, 0x0f, 0x1f, 0x8f, 
	0x0f, 0x1f, 0x8f, 0x0f, 0xbf, 0xcf, 0x0f, 0xff, 0xff, 0x0f, 0xff, 0xff, 0x0f, 0x9e, 0x9f, 0x07, 
	0x3c, 0xc0, 0x03, 0x00, 0x00, 0x00, 0x00, 0x00, 0x00, 0x00, 0x00, 0x00
};
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

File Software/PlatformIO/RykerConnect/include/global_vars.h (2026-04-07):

#pragma once

#include <Arduino.h>
#include <U8g2lib.h>
#include <SPI.h>
#include <DS3231.h>
#include <Preferences.h>
#include <mcp9808.h>
#include <freertos/semphr.h>

#define DEBUG
#define SPLASHSCREEN

#define VERSION 0x0007
#define HARDWARE_VERSION "ESP32S3-REV01"

#define OLED_WIDTH 320
#define OLED_HEIGHT 132

#define FIRSTSCROLL_INTERVAL 5000
#define SCROLL_INTERVAL 800
#define RESET_INTERVAL 45000
#define TIME_INTERVAL 1000
#define TEMP_INTERVAL 30000


#define SUN	0
#define SUN_CLOUD  1
#define CLOUD 2
#define RAIN 3
#define THUNDER 4


#pragma region BLE UUIDS

#define SERVICE_UUID "db7ba582-229a-4b96-9000-cf0f69f86f73"

#define TIME_UUID "a41dcc81-d45e-4445-99bb-38c37c1ef1c8"
#define NETWORK_UUID "49c7fba8-9ba7-474b-b8a5-a5431e057e23"
#define PHONE_BATTERY_UUID "1f74ccf5-376a-40b6-ab60-7b1c5efbf652"
#define INTERCOM_BATTERY_UUID "85546838-6ae5-45cb-aa2f-4c8af50d17d4"
#define MEDIA_DATA_UUID "dcadc0d8-24ed-40ed-952b-5d1c872a69aa"
#define NOTIFICATION_UUID "755cf5b1-ded3-4c7b-a6fc-8c5ce2f99fdb"


#define SCREEN_UUID "62dbb02d-4a3a-452e-b753-02bcb2272b9d"
#define DISPLAY_BRIGHTNESS_UUID "7bc28f30-10bc-46e2-b84b-96e0545c2f5c"
#define SETTINGS_UUID "05f7c3e4-daac-4953-8c71-20eacdf0c7a1"
#define FIRMWARE_UPDATE_UUID "1d1306c5-98d9-4998-8dfd-35136295575f"
#define FIRMWARE_RESET_UUID "18cb54fe-45e8-4819-a262-24b731c8b236"
#define DISPLAY_REINIT_UUID "3a6e4b2c-8f71-4d09-b5a3-c7e2f1d08a94"
#define FIRMWARE_VERSION_UUID "fb2385da-5290-4513-bb0c-6d0b21de619a"
#define HARDWARE_VERSION_UUID "3ae9aece-1b67-4281-a53b-748adf23f484"
#define VOLUME_UUID "c4e83b7d-5a12-4f8e-b9d6-3e7f1c2a4b8d"

#pragma endregion  


//U8G2_SSD1322_NHD_256X64_F_4W_HW_SPI u8g2(U8G2_R0, /* cs=*/ 5, /* dc=*/ 4, /* reset=*/ -1);
extern U8G2_SSD1320_160X132_F_4W_HW_SPI u8g2_0; 
extern U8G2_SSD1320_160X132_F_4W_HW_SPI u8g2_1; 
extern U8G2 *u8g2_current;
extern u8g2_uint_t offset;


extern DS3231 RTC;
extern MCP9808 ts;
extern const int lightSensorPin;
extern String global_time;
extern float global_temp;
extern unsigned long previousMusicMillis;  // will store last time LED was updated
extern unsigned long previousBatteryIconMillis; //Change Battery Icon
extern unsigned long previousResetMillis; //Change Battery Icon
extern unsigned long previousTimeMillis;
extern unsigned long previousTempMillis;
extern int8_t batteryIconSelection;

extern uint16_t resetPin;


extern int8_t phone_battery_level;
extern int8_t intercom_battery_level;
extern bool phone_battery_status;
extern bool intercom_battery_status;
extern const unsigned short musicInterval;
extern uint8_t network_signal;
extern String network_type;
extern bool blConnected;
extern uint8_t screenToDisplay;
extern bool pairingActive;
extern uint32_t pairingPin;
extern unsigned long pairingConnectTime;

extern SemaphoreHandle_t dataMutex;

#pragma region Firmware Update

#define WIFI_HOSTNAME "RykerConnect"
extern bool firmwareUpdateEnabled;
extern bool firmwareDownloadAttempted;
extern int8_t otaDownloadPercent;
extern String wifiIPAddress;
extern String firmwareDownloadUrl;

#pragma endregion

#pragma region Notification Variables

extern unsigned long previousNotificationMillis;
extern bool notificationDisplayed;

extern String notificationType;
extern String notificationTitle;
extern String notificationText;

#pragma endregion

#pragma region Music Variables
extern bool playstate;
extern uint16_t music_timer;
extern uint16_t music_length;
extern String music_title;
extern String music_artist;

extern uint8_t scroll_title;
extern uint8_t scroll_artist;
extern bool scroll_title_en;
extern bool scroll_artist_en;
extern unsigned long previousScrollTitleMillis;
extern unsigned short scrollTitleInterval;
extern unsigned long previousScrollArtistMillis;
extern unsigned short scrollArtistInterval;
#pragma endregion

#pragma region Settings

#define ADAPTIVE_BRIGHTNESS         0
#define DISPLAY_BRIGHTNESS          148
#define SCREEN_SELECTION            1
#define SUB_SCREEN_SELECTION        0
#define BATTERY_ICON_SELECTION1     1
#define BATTERY_ICON_SELECTION2     1
#define BATTERY_ICON_SELECTION3     0
#define BATTERY_ICON_SELECTION4     0
#define BATTERY_ICON_FIRST          0
#define BATTERY_ICON_INTERVAL       30000
#define NOTIFICATION_INTERVAL       20000
#define LOW_BATTERY_THRESHOLD_PHONE_DEFAULT    20
#define LOW_BATTERY_THRESHOLD_INTERCOM_DEFAULT 20
#define AUTO_BRIGHTNESS_ADC_LOW_DEFAULT         200
#define AUTO_BRIGHTNESS_ADC_HIGH_DEFAULT        3500
#define WARNING_POPUP_DURATION_DEFAULT          5
#define VOLUME_POPUP_DURATION_DEFAULT           3

extern Preferences prefs;
extern struct EEPROM_Struct{
    // Brightness
    bool        adaptive_brightness;
    uint8_t     display_brightness;
    uint16_t    auto_brightness_adc_low;   // ADC value (0-4095) -> min brightness
    uint16_t    auto_brightness_adc_high;  // ADC value (0-4095) -> max brightness
    // Screen
    uint8_t     screen;
    uint8_t     sub_screen;
    // Battery icon
    bool        battery_icon_selection[4]; //2 bool reserved
    int8_t      battery_icon_first;
    uint32_t    battery_icon_interval;
    // Low battery warning
    uint8_t     low_battery_threshold_phone;
    uint8_t     low_battery_threshold_intercom;
    uint8_t     warning_popup_duration;  // seconds, for all warning popups
    // Other
    uint32_t    notification_interval;
    float       temp_calibration; // degrees to subtract from sensor reading
    // Reserved for future use
    uint8_t     reserved[10];
    uint32_t    crc;
}__attribute__((packed)) sEEPROM;


#pragma endregion

#pragma region Volume Variables
extern uint8_t volumeLevel;
extern bool volumeDisplayed;
extern unsigned long previousVolumeMillis;
#pragma endregion

#pragma region Auto-Brightness
#define AUTO_BRIGHTNESS_INTERVAL 100
#define AUTO_BRIGHTNESS_MIN 25
#define AUTO_BRIGHTNESS_MAX 255
extern unsigned long previousAutoBrightnessMillis;
extern float smoothedLightLevel;
#pragma endregion

#pragma region BLE Watchdog
#define BLE_STALE_TIMEOUT 600000
extern unsigned long lastBLEActivityMillis;
#pragma endregion

#pragma region Low Battery Warning
extern bool lowBatteryDisplayed;
extern unsigned long previousLowBatteryMillis;
extern String lowBatteryText;
extern bool lowBatteryTriggeredPhone;
extern bool lowBatteryTriggeredIntercom;
#pragma endregion
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

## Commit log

2024-11-24 Initial Upload
    Initial Upload, REV01 has a HARDWARE Bug! - Not recommended.
    [DisplayCover V1.3mf, PCB-Mount.-Back V1.3mf, RykerConnect - DevMount v1.FCStd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]
2026-04-03 Update Firmware and APK
    Add Features to Apk to utilize functions already implemented in firmware.
    Stability improvments to firmware and app.
    Add "automatic" firmware updater, to download update from github.
    [RykerConnect.kicad_pcb, RykerConnect.kicad_sch, bom.csv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]
2026-04-03 update buttons hiding
2026-04-05 fix ble hostname not beeing advertised, updated version number
    [global_vars.h]
2026-04-05 update pcb to schematics
    [RykerConnect.kicad_pcb, RykerConnect.kicad_sch, bom.csv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]
2026-04-06 add volume and hardware version ble functions, low battery warnings, implement auto brightness, ble timeout
2026-04-06 update rev 2
    [RykerConnect.kicad_pcb]
2026-04-06 source for firmware 00.06, see changelog for changes
    [partitions_spiffs_1mb.csv, partitions_spiffs_500kb.csv]
2026-07-28 update SDK to 37 and Gradle 9.6.1 + companion device service permission and receiver cleanup
2026-07-28 cleanup permissions and move ChargeStateReceiver to dynamic registration
2026-07-28 support multiple intercoms with priority and add new app settings screen
    * **Intercoms:** Implement multi-selection for intercoms with a priority-based system (the highest connected device in the list is active).
    * **Settings:** Add a new `AppSettingsScreen` to toggle Material You dynamic colors and the visibility of the debug card.
    * **Logic:** Refactor `BluetoothConnectReceiver` to use `goAsync()` for non-blocking processing and improve battery level polling with retry logic.
    * **Data:** Update `RykerConnectStore` to handle encoded MAC lists and provide legacy migration for existing single-device setups.
    * **UI:** Update the intercom card and selection dialog to support checkboxe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
2026-07-28 reduce background wakeups and make charge state tracking configurable
    Replace the endless 5s media session poll with callback-driven discovery,
    idle the intercom loop when nothing is selected, and switch the default
    charge state source to POWER_CONNECTED/DISCONNECTED plus a configurable
    poll interval. The BATTERY_CHANGED receiver stays available as an option.
2026-07-28 morph the settings icon into the app settings overlay
    The gear button had no shared element, so the app settings screen faded in
    while update, service and intercom morph out of their trigger. Adds the
    matching sharedBounds pair under the key "app-settings-bounds".
2026-07-28 scale the app settings overlay out of the gear icon
    The previous sharedBounds pair did not animate: verified on a Pixel 10 / API 37
    emulator at 10x animator duration scale, the overlay cross-faded at full size
    with no bounds interpolation. The same holds for the existing service, update
    and intercom pairs, so matching them would not have helped.
    Replaces it with scaleIn/scaleOut anchored at TransformOrigin(1f, 0f) - the
    corner the gear sits in - so the screen visibly grows out of the button.
2026-07-28 fix shared element transitions by ordering sharedBounds before size modifiers
    None of the overlays actually morphed - verified on a Pixel 10 / API 37 emulator
    at 10x animator duration scale: update, service, settings and intercom all
    cross-faded at full size with no bounds interpolation.
    Cause is modifier order. Modifier.fillMaxSize().sharedBounds(...) puts the size
    modifier outside, so the bounds are already fixed by the time sharedBounds runs
    and there is nothing left to interpolate. Same for fillMaxWidth in ServiceCard.
    Moves sharedBounds ahead of the size modifiers on all five pairs and gives the
    app settings overlay a 420 ms bounds transform with Crop/TopEnd scaling, so the
    gear icon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
2026-07-28 soften the content fade of the service overlay morph
    With the default sharedBounds enter/exit the settings screen was already fully
    opaque while the container was still growing, which read as an abrupt cut.
    Delays and lengthens the content fade (340 ms after 110 ms) so the container
    expands first, and fades the button label out early on the card side.
2026-07-28 clear the remaining IDE inspections
    Android Studio's Code Analysis is a superset of Gradle lint; these are IntelliJ
    inspections the compiler and lint do not report.
    - Unused imports (Context, BatteryManager) and the unused NavController
    parameter of HomeScreen, plus its argument in MainActivity
    - Unused setBatteryStatus parameter of IntercomCard and its argument
    - Unused intercomClick/mainUnitClick in HomeViewModel
    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
2026-07-28 drop the orphaned intercomBatteryEnabled local
    The value was read inside the first serviceScope.launch, but the intercom
    battery loop is started from a second, separate coroutine that cannot see that
    local and therefore reads the toggle itself. The copy was never consumed.
    Keeping the two coroutines separate is deliberate: the first one returns early
    when a connection already exists, so folding the intercom start into it would
    skip the loop on reconnects.
2026-07-28 speed up the overlay morphs, fix the debug card ripple, add predictive back
    Motion: service and intercom ran on the default spring, which needs roughly half
    a second to settle. Both now share a 300 ms curve in OverlayMotion.kt, and the
    app settings morph drops from 420 to 340 ms. The curve has to be set on both
    sides of a pair - opening uses the overlay's, closing uses the card's.
    Debug card: the card's 12 dp padding sat outside the Column, so the clickable Row
    was inset on all sides and the highlight showed as a box around the label and the
    arrow. Padding moved inside the clickable, so the ripple now fills the card.
    Predictive back: replaces BackHandler with PredictiveBackHandler on the t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
2026-07-28 update to v1.4.0: multi-intercom support, battery polling config, and performance improvements
